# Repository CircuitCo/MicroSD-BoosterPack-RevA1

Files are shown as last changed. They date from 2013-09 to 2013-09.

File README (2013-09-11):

The microSD BoosterPack allows you to add mass storage to your Launchpad design for data logging and program storage.  The design uses the Launchpad's SPI interface to communicate with the microSD card. Jumper blocks are provided to set which GPIOs are used for the microSD card's chip select and card detect signals. The board is equipped with stackable connectors, which means it can be used with other BoosterPacks. The Micro SD BoosterPack is compatible with the MSP430 LaunchPad, Tiva C LaunchPad (previously Stellaris). This board is designed by Sakoman Inc. For more information on the designer, please visit http://www.sakoman.com/.

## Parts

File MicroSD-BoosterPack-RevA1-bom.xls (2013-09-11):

MICRO SD BOOSTERPACK REV A1
QTY | REF DES | DESCRIPTION | PACKAGE | MAN | MAN P/N | VENDOR | VENDOR P/N
1 | C1 | CAP CER 22UF 16V 20% X5R 1206 | 1206 | TAIYO | EMK316BJ226ML-T | DIGI-KEY | 587-1433-1-ND
1 | C2 | CAP CER 0.1UF 16V 10% X7R 0603 | 603 | KEMET | C0603C104K4RACTU | DIGI-KEY | 399-1096-2-ND
1 | R1 | RES 2 OHM 1/10W 5% 0603 SMD | 603 | PANASONIC | ERJ-3GEYJ2R0V | DIGI-KEY | P2.0GTR-ND
1 | U1 | CONN MINI MICRO-SD 8PIN PCB GOLD | SMT socket | AMPHENOL | 101-00660-68-6 | DIGI-KEY | 101-00660-68-6-1-ND
2 | J1/3, J4/2 | 2.54 FEMALE HEADER DIP STRAIGHT HEIGHT=8.5MM 2X10 DIP=10.5mm GOLD | 2x10 0.1 thru-hole | MLE | SSHQ-110-D-08-F-LF
2 | J5, J6 | CONN HEADER 8POS .100 STR 30AU | 2x4 0.1 thru-hole | FCI | 68602-108HLF | DIGI-KEY | 609-3362-ND
2 |  | CONN JUMPER SHORTING .100” GOLD |  | SULLINS | QPC02SXGN-RC | DIGI-KEY | S9337-ND
 |  | PCB SI-10005 Rev A1, 2 layers 0.062" FR4 1 oz copper, red SM, ENIG

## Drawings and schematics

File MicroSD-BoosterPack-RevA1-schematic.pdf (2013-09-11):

A

A

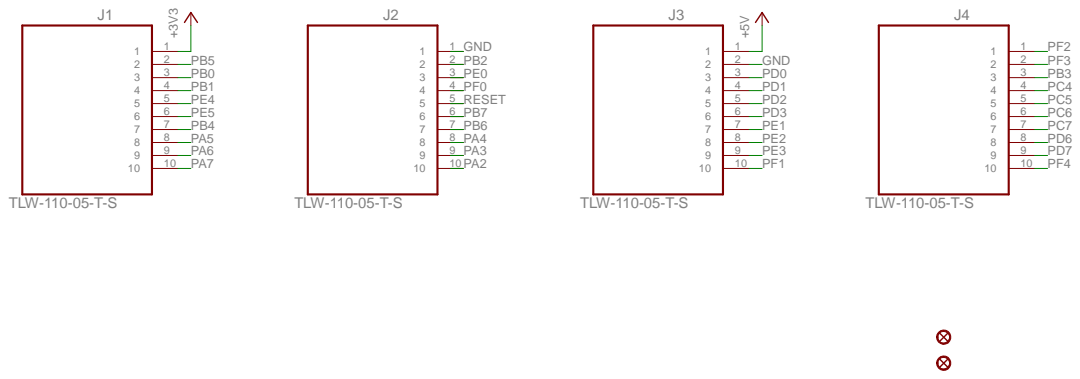
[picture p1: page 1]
TLW-110-05-T-S; GND; PE0 PF0 RESET PB7 PB6 PA4 PA3 PA2

A

A

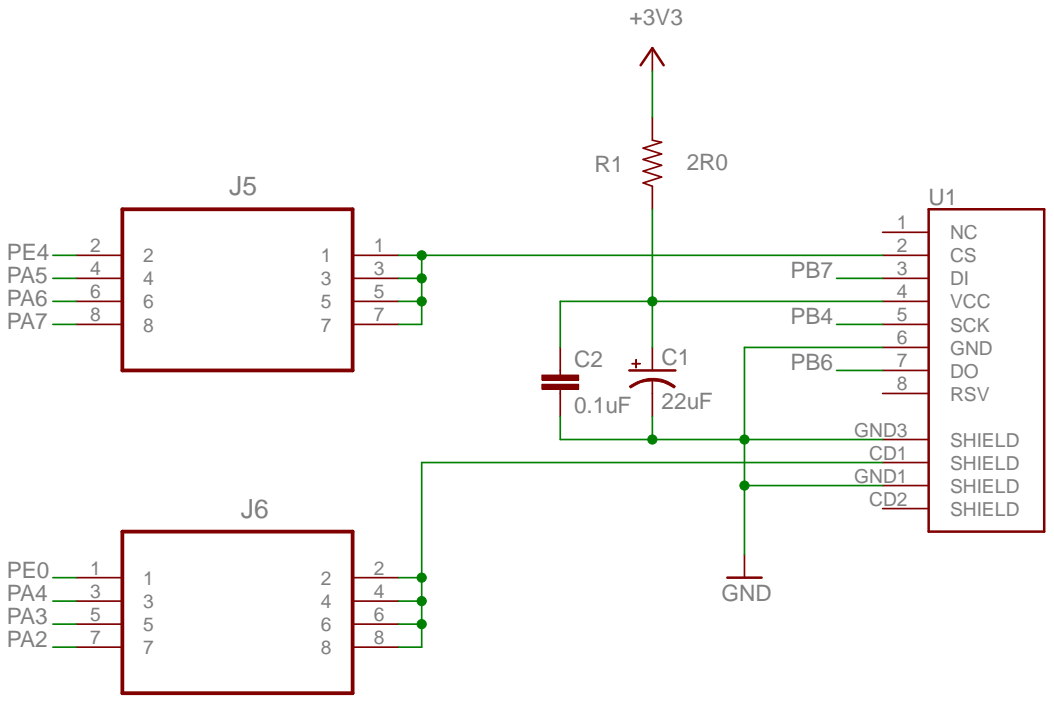
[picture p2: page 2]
GND; GND 6; VCC 4 SCK 5; RSV 8; SHIELD GND1; SHIELD GND3 SHIELD CD1; SHIELD CD2

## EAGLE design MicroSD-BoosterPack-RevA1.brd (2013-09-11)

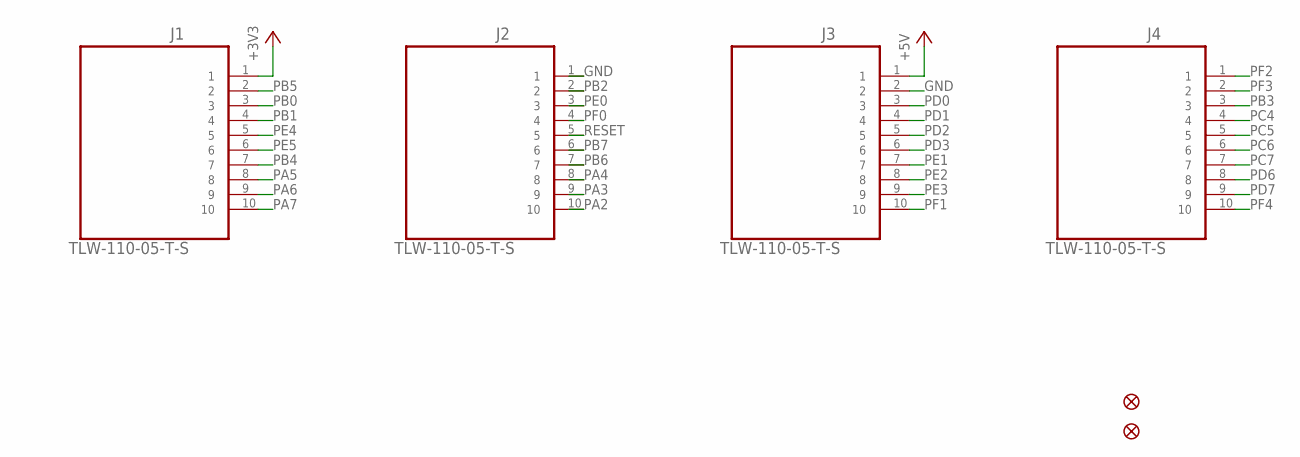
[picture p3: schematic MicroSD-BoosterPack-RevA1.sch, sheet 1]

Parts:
FID1, FID2: FIDUCIAL1X2; FIDUCIAL-1X2
J1: TLW-110-05-T-S; SAMTEC_TLW-110-05-T-S
J2, J3, J4: TLW-110-05-T-S; SAMTEC_TLW-110-05-T-S; MPN TLW-110-05-T-S

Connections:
+3V3: J1.1; also elsewhere on the board
+5V: J3.1
GND: J2.1, J3.2; also elsewhere on the board
PA2: J2.10; also elsewhere on the board
PA3: J2.9; also elsewhere on the board
PA4: J2.8; also elsewhere on the board
PA5: J1.8; also elsewhere on the board
PA6: J1.9; also elsewhere on the board
PA7: J1.10; also elsewhere on the board
PB0: J1.3
PB1: J1.4
PB2: J2.2
PB3: J4.3
PB4: J1.7; also elsewhere on the board
PB5: J1.2
PB6: J2.7; also elsewhere on the board
PB7: J2.6; also elsewhere on the board
PC4: J4.4
PC5: J4.5
PC6: J4.6
PC7: J4.7
PD0: J3.3
PD1: J3.4
PD2: J3.5
PD3: J3.6
PD6: J4.8
PD7: J4.9
PE0: J2.3; also elsewhere on the board
PE1: J3.7
PE2: J3.8
PE3: J3.9
PE4: J1.5; also elsewhere on the board
PE5: J1.6
PF0: J2.4
PF1: J3.10
PF2: J4.1
PF3: J4.2
PF4: J4.10
RESET: J2.5

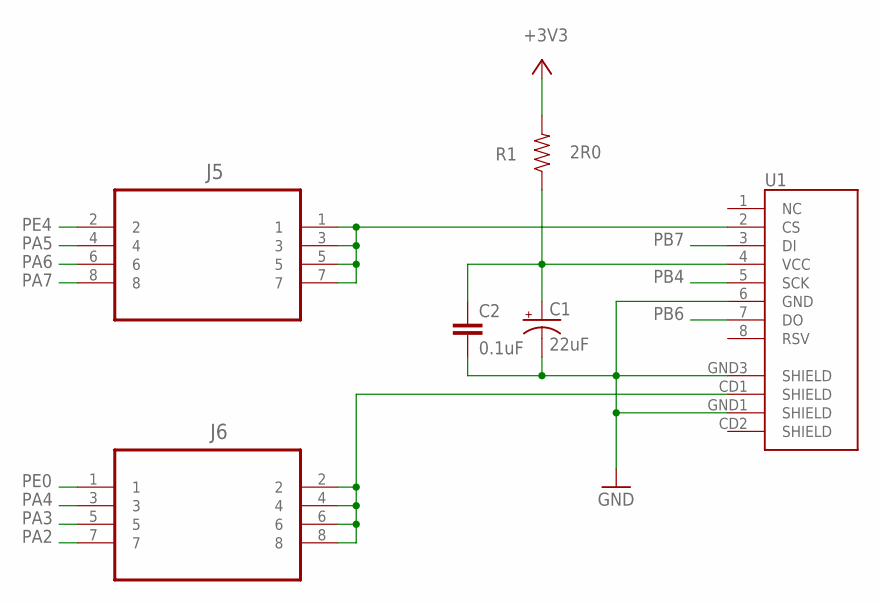
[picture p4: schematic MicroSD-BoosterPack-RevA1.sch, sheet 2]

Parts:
C1: 22uF; EIA3216
C2: 0.1uF; 0603-CAP
J5, J6: SLW-104-01-T-D; SAMTEC_SLW-104-01-T-D
R1: 2R0; 0603-RES
U1: USD-SOCKETNEW; MICRO-SD-SOCKET-PP

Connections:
+3V3: R1.2; also elsewhere on the board
+3V3F: C1.A (+), C2.1, R1.1, U1.4 (VCC)
GND: C1.C (-), C2.2, U1.6 (GND), U1.GND1 (SHIELD), U1.GND3 (SHIELD); also elsewhere on the board
unnamed: J6.2, J6.4, J6.6, J6.8, U1.CD1 (SHIELD)
unnamed: J5.1, J5.3, J5.5, J5.7, U1.2 (CS)
PA2: J6.7; also elsewhere on the board
PA3: J6.5; also elsewhere on the board
PA4: J6.3; also elsewhere on the board
PA5: J5.4; also elsewhere on the board
PA6: J5.6; also elsewhere on the board
PA7: J5.8; also elsewhere on the board
PB4: U1.5 (SCK); also elsewhere on the board
PB6: U1.7 (DO); also elsewhere on the board
PB7: U1.3 (DI); also elsewhere on the board
PE0: J6.1; also elsewhere on the board
PE4: J5.2; also elsewhere on the board

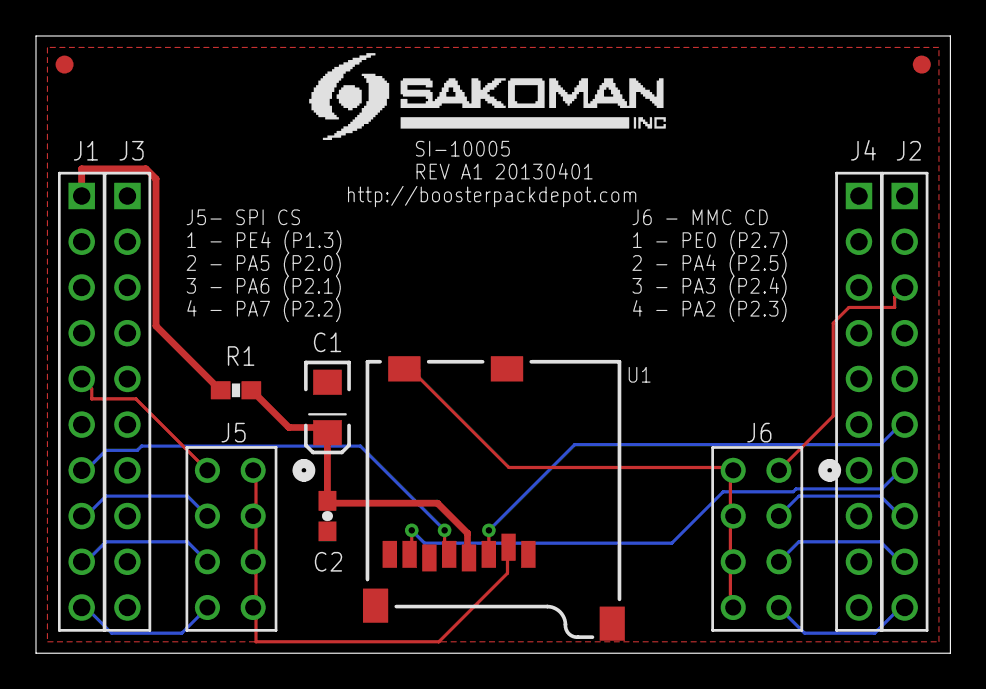
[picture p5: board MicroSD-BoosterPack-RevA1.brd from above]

Board: 2 copper layers, 50.8 x 34.3 mm, 12 parts (0 on the bottom side), 16 nets.

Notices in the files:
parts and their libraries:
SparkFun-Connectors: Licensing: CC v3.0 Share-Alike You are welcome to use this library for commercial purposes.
